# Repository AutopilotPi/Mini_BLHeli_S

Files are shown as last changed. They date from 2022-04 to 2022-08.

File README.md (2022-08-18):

# Mini_BLHeli_S

The repo is a hardware design for BLHeli BLDC Driver(https://github.com/bitdump/BLHeli) by Kicad 6.0. The design aim to construct a 
SMT module which could be integrated into PCB of Flight Controller or some other DIY projects easily. 

- Pinout class: J
- freq class: H (48Mhz)
- delay class : above 20
- mos: N + P (so there are no mos drivers)
- voltage: 1s-3s(which is limited by LDO, if you use the input 3V3 and don't solder the LDO, then you could use higher voltage. Please be care about withstand voltage of 
input capacities) 

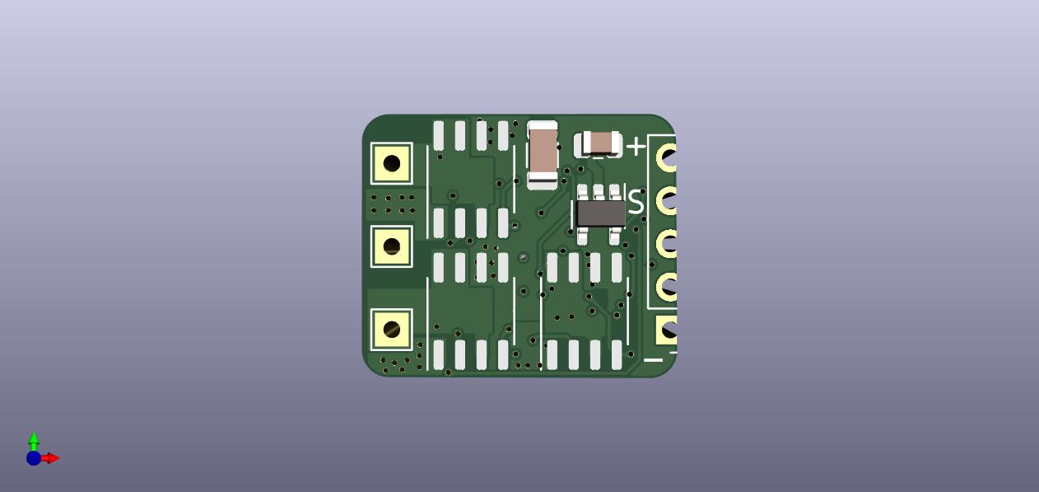
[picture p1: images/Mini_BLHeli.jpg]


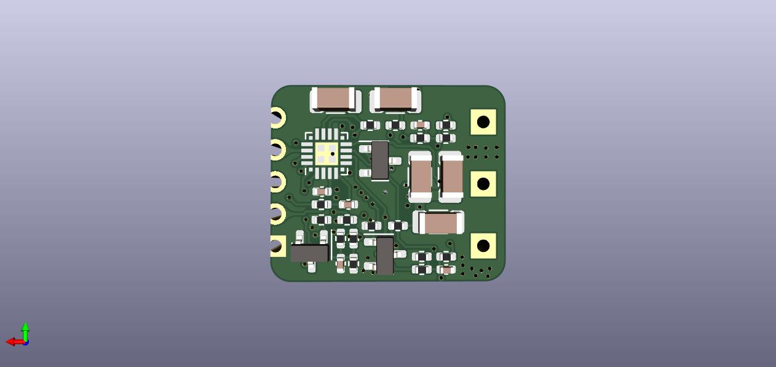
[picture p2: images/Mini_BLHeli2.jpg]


## License
Please notice that the license of this project is GPL 3.0. For hardware project, hope that you can share the changes if you make something different in the sch or pcb.

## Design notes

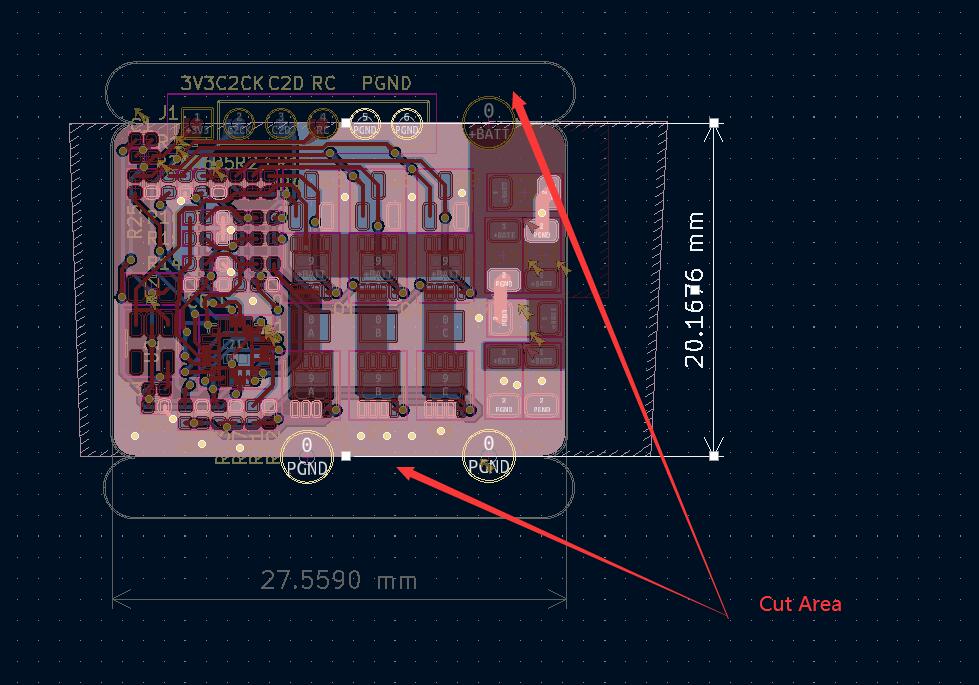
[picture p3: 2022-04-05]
images/Mini_BLHeli_cut_area.jpg

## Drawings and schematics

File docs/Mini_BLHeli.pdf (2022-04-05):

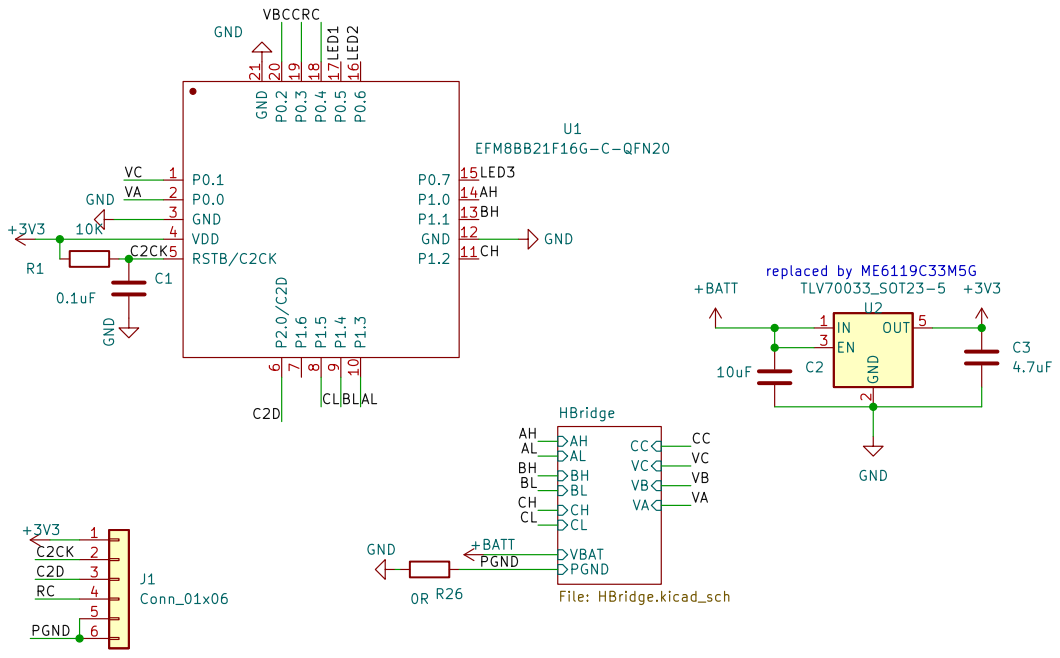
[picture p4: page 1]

2 EN 3 OUT 5 U2 TLV70033_SOT23-5 +BATT R26 0R GND GND

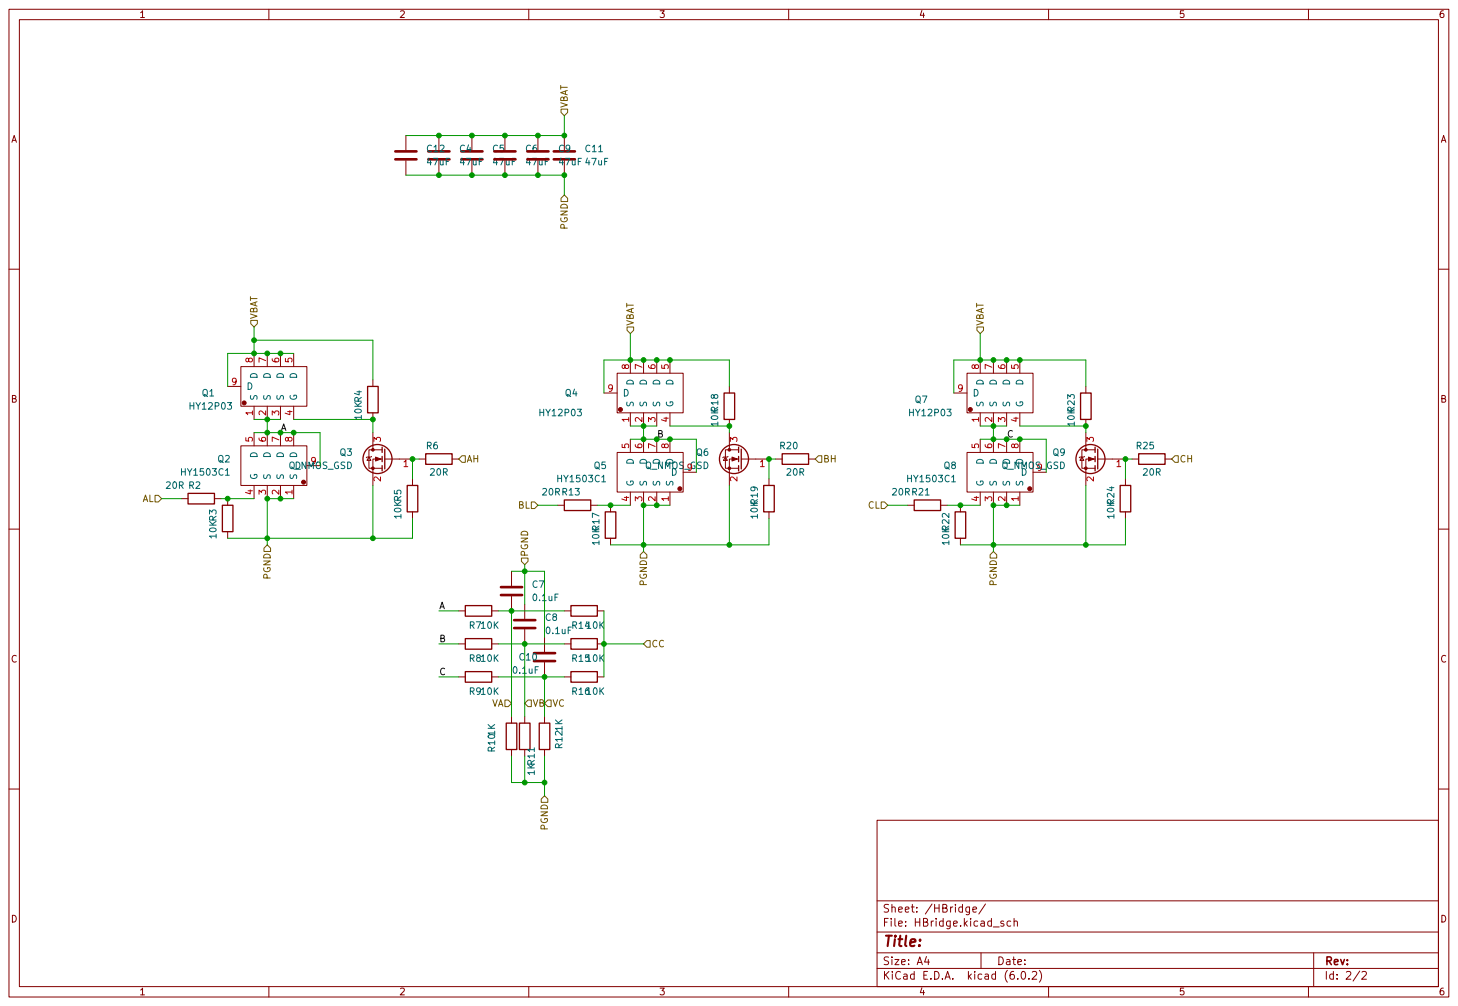
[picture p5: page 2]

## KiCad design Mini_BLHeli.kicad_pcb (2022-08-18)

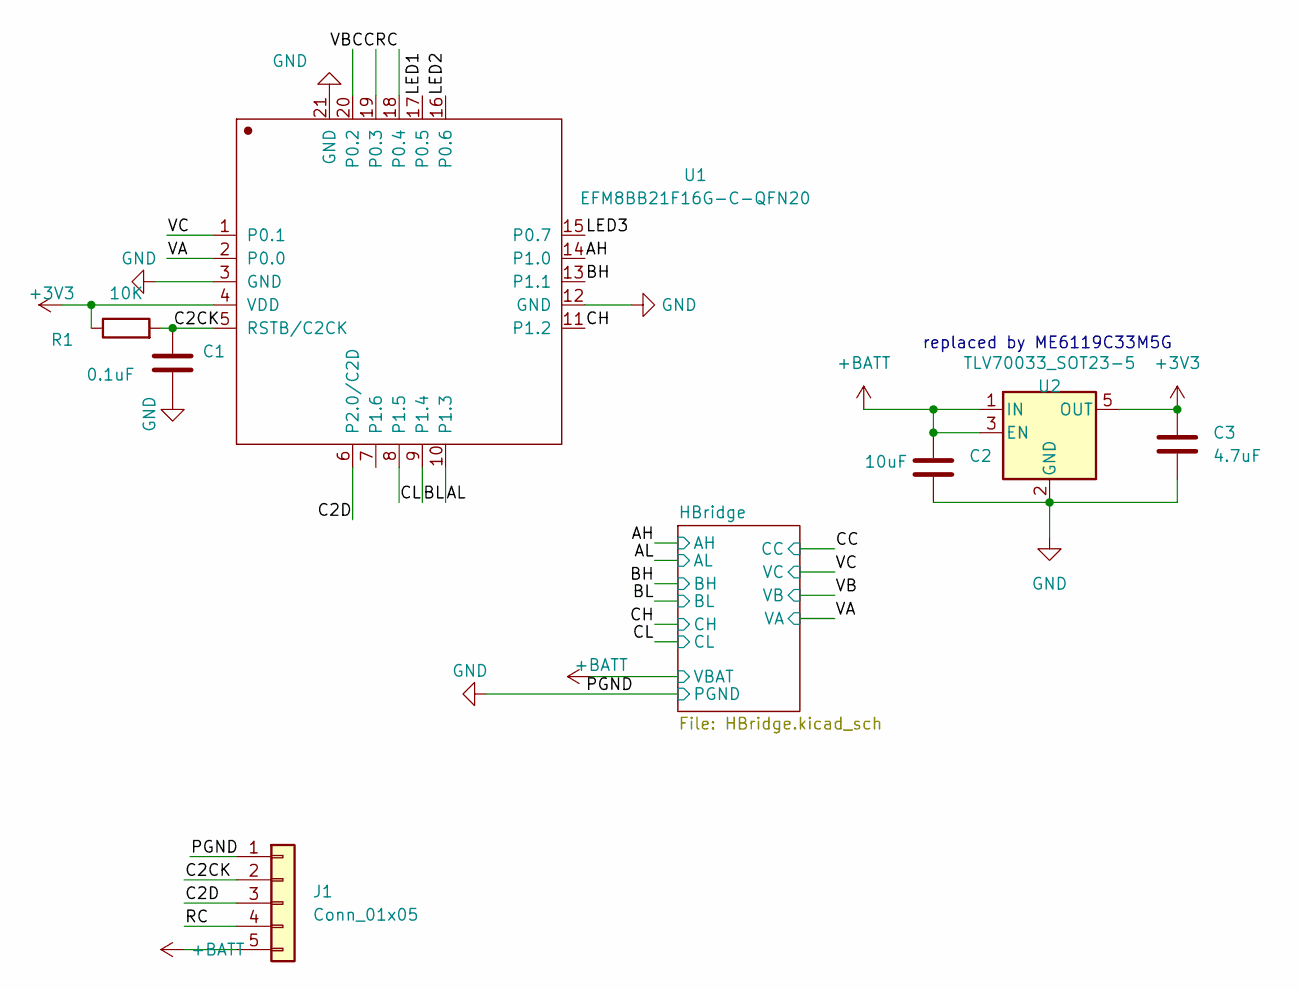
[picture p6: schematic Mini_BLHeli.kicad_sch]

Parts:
C1: 0.1uF; C_0402_1005Metric
C2: 10uF; C_0805_2012Metric
C3: 4.7uF; C_0402_1005Metric
J1: Conn_01x05; PinHeader_1x05_P2.54mm_Vertical
R1: 10K; R_0402_1005Metric
U1: EFM8BB21F16G-C-QFN20; SiliconLabs_QFN-20-1EP_3x3mm_P0.5mm_EP1.8x1.8mm
U2: TLV70033_SOT23-5; SOT-23-5

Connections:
+3V3: C3.1, R1.1, U1.4 (VDD), U2.5 (OUT)
+BATT: C2.1, J1.5, U2.1 (IN), U2.3 (EN); also elsewhere on the board
/AH: U1.14 (P1.0); also elsewhere on the board
/AL: U1.10 (P1.3); also elsewhere on the board
/BH: U1.13 (P1.1); also elsewhere on the board
/BL: U1.9 (P1.4); also elsewhere on the board
/C2CK: C1.1, J1.2, R1.2, U1.5 (RSTB/C2CK)
/C2D: J1.3, U1.6 (P2.0/C2D)
/CC: U1.19 (P0.3); also elsewhere on the board
/CH: U1.11 (P1.2); also elsewhere on the board
/CL: U1.8 (P1.5); also elsewhere on the board
/LED1: U1.17 (P0.5)
/LED2: U1.16 (P0.6)
/LED3: U1.15 (P0.7)
/RC: J1.4, U1.18 (P0.4)
/VA: U1.2 (P0.0); also elsewhere on the board
/VB: U1.20 (P0.2); also elsewhere on the board
/VC: U1.1 (P0.1); also elsewhere on the board
GND: C1.2, C2.2, C3.2, J1.1, U1.3 (GND), U1.12 (GND), U1.21 (GND), U2.2 (GND); also elsewhere on the board

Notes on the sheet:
replaced by ME6119C33M5G

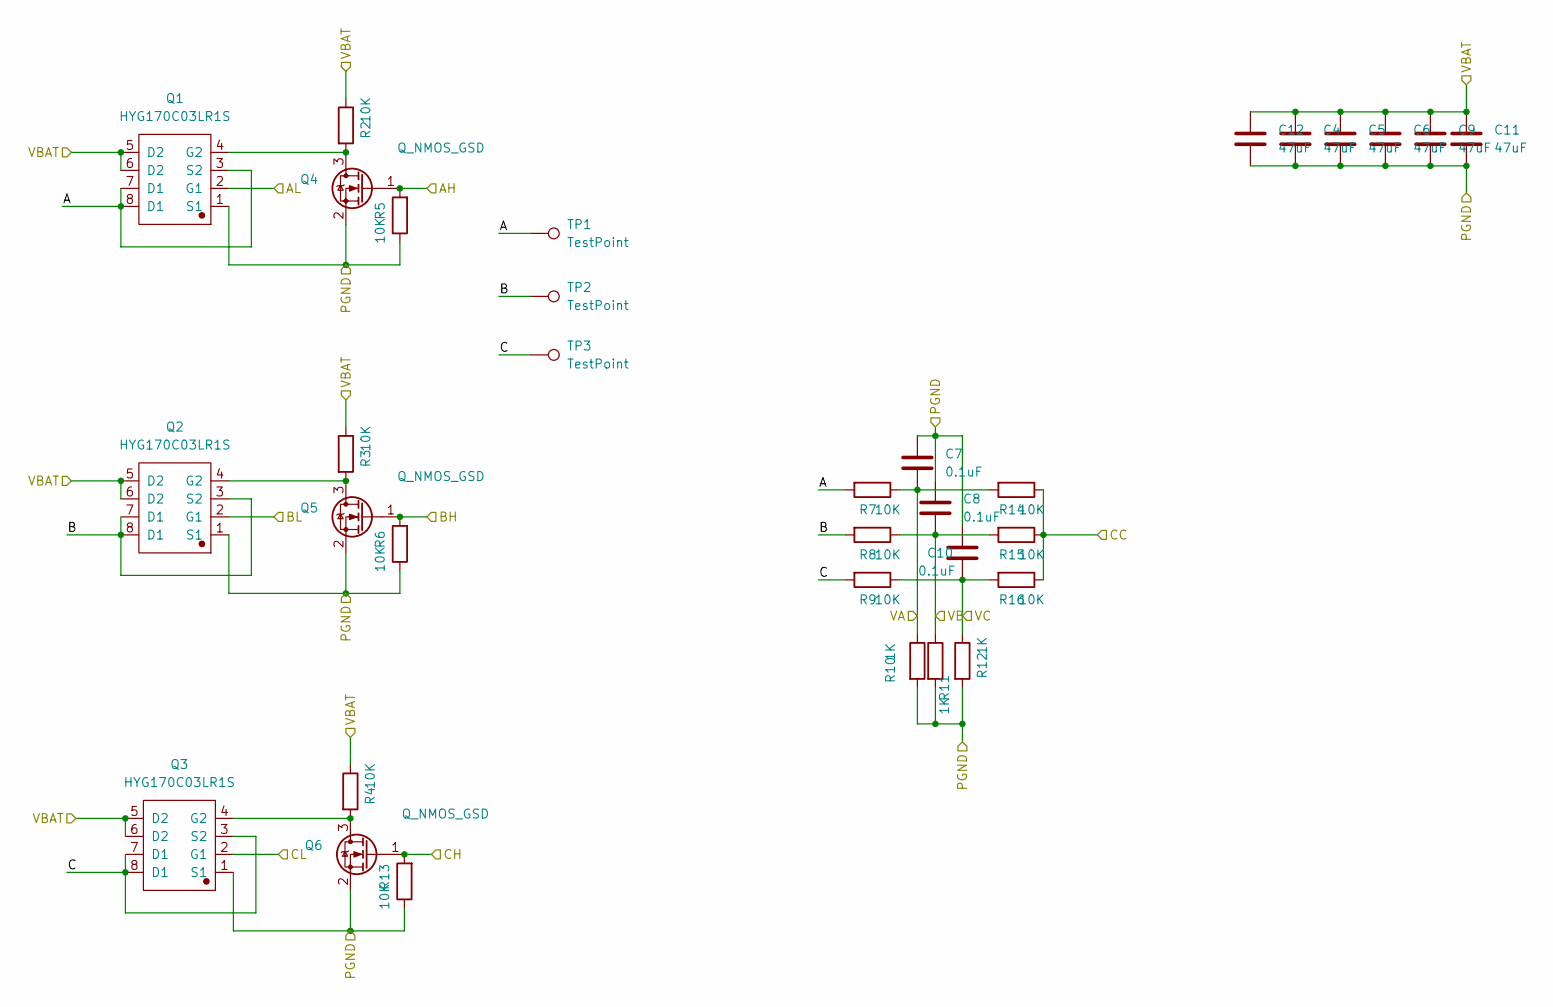
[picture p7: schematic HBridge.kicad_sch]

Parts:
C4, C5, C6, C9, C11, C12: 47uF; C_1206_3216Metric
C7, C8, C10: 0.1uF; C_0402_1005Metric
Q1, Q2, Q3: HYG170C03LR1S; SO-8_3.9x4.9mm_P1.27mm
Q4, Q5, Q6: Q_NMOS_GSD; SOT-23
R2, R3, R4, R5, R6, R7, R8, R9, R13, R14, R15, R16: 10K; R_0402_1005Metric
R10, R11, R12: 1K; R_0402_1005Metric
TP1, TP2, TP3: TestPoint; TestPoint_THTPad_2.0x2.0mm_Drill1.0mm

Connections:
+BATT: C4.1, C5.1, C6.1, C9.1, C11.1, C12.1, Q1.5 (D2), Q1.6 (D2), Q2.5 (D2), Q2.6 (D2), Q3.5 (D2), Q3.6 (D2), R2.1, R3.1, R4.1; also elsewhere on the board
/AH: Q4.1 (G), R5.2; also elsewhere on the board
/AL: Q1.2 (G1); also elsewhere on the board
/BH: Q5.1 (G), R6.2; also elsewhere on the board
/BL: Q2.2 (G1); also elsewhere on the board
/CC: R14.1, R15.1, R16.1; also elsewhere on the board
/CH: Q6.1 (G), R13.2; also elsewhere on the board
/CL: Q3.2 (G1); also elsewhere on the board
/HBridge/A: Q1.3 (S2), Q1.7 (D1), Q1.8 (D1), R7.2, TP1.1
/HBridge/B: Q2.3 (S2), Q2.7 (D1), Q2.8 (D1), R8.2, TP2.1
/HBridge/C: Q3.3 (S2), Q3.7 (D1), Q3.8 (D1), R9.2, TP3.1
/VA: C7.1, R7.1, R10.1, R14.2; also elsewhere on the board
/VB: C8.1, R8.1, R11.1, R15.2; also elsewhere on the board
/VC: C10.1, R9.1, R12.1, R16.2; also elsewhere on the board
GND: C4.2, C5.2, C6.2, C7.2, C8.2, C9.2, C10.2, C11.2, C12.2, Q1.1 (S1), Q2.1 (S1), Q3.1 (S1), Q4.2 (S), Q5.2 (S), Q6.2 (S), R5.1, R6.1, R10.2, R11.2, R12.2, R13.1; also elsewhere on the board
unnamed: Q1.4 (G2), Q4.3 (D), R2.2
unnamed: Q2.4 (G2), Q5.3 (D), R3.2
unnamed: Q3.4 (G2), Q6.3 (D), R4.2

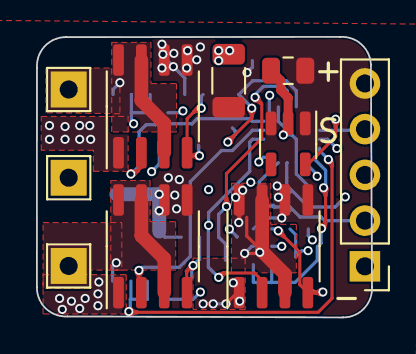
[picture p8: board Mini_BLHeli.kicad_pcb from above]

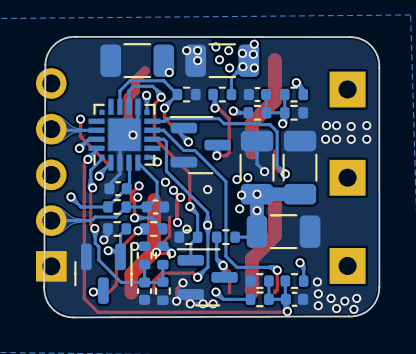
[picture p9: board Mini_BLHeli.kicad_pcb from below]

Board: 4 copper layers, 18.6 x 15.6 mm, 40 parts (30 on the bottom side), 22 nets.

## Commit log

2022-04-04 v0.9 finish
    [HBridge.kicad_sch, Mini_BLHeli.kicad_pcb, Mini_BLHeli.kicad_sch]
2022-04-05 add images
    [Mini_BLHeli.kicad_pcb]
2022-04-05 add docs
    [Mini_BLHeli.kicad_pcb]
2022-08-18 update for new version
    [HBridge.kicad_sch, Mini_BLHeli.kicad_pcb, Mini_BLHeli.kicad_sch]
